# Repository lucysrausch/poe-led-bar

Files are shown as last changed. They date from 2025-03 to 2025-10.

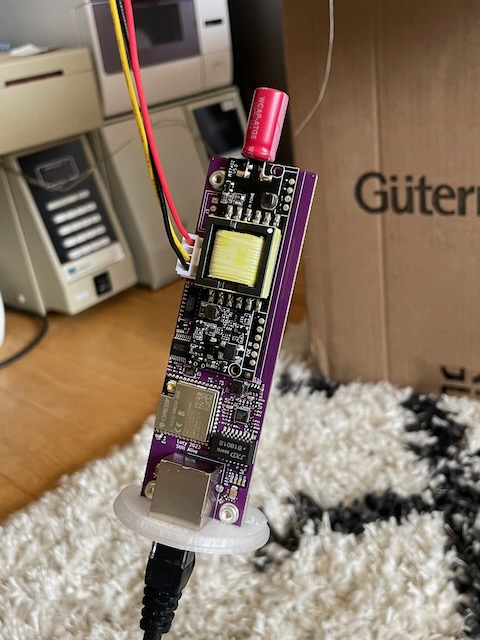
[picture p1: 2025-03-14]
media/pcba.jpeg

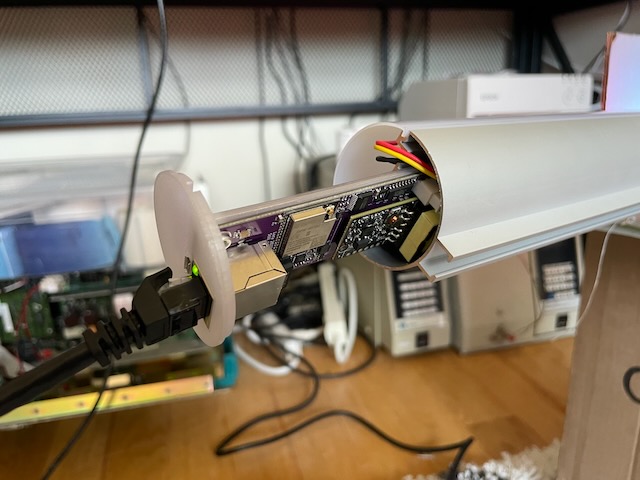
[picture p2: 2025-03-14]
media/cover.jpeg

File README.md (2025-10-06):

# poe-led-bar

Important! I did not have a chance to write docs for this project yet, so:
The hardware is proven at this point and people have successfully ordered and used PCBs based off this repo, with one exception.

The PCB design has a minor bug with the polarity of one of the LEDs inside the ethernet jack.
In rev1.0 of the PCB design, this is not only causing the LED to not work but also the entire ethernet link, because the LEDs are also used as strapping pins to configure the PHY.

The workaround I used is to use this RJ45 jack, which has a bicolor LED so polarity doesn't matter:
https://www.digikey.com/en/products/detail/adam-tech/MTJ-88TX1-FSD-LV/9832786
You could use https://www.digikey.com/en/products/detail/adam-tech/MTJ-88TX1-LV/9832558 which is in stock.

If you dont particularly care about the LEDs in the jack, you can also just get a passive jack without LEDs and solder a 1k SMD resistor across the pads for the LEDs. That should also work fine to configure the PHY.

I will fix this in a future release so more common jacks like the ones stocked at JLC and LCSC can be used.

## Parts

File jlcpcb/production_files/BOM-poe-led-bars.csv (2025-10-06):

Comment | Designator | Footprint | LCSC
FB | FB1 | C_0603 | C1002
1k | R11,R19,R41,R42 | R_0402 | C11702
100n | C1,C15,C20,C21,C25,C3,C5 | C_0402 | C1525
27p | C26,C27 | C_0402 | C1557
100n 100V | C6,C7,C8,C9 | C_0603 | C15725
4u7 | L2 | L_Bourns-SRN4018 | C167828
22k1 | R32 | R_0402 | C170263
4u7 | C16,C19 | C_0603 | C19666
22 | R12,R13,R14,R15,R16,R18,R27,R30,R31,R33,R34,R5 | R_0402 | C25092
49R9 | R6,R7,R8,R9 | R_0402 | C25120
75R | R21,R22,R23,R24 | R_0402 | C25133
100k | R29 | R_0402 | C25741
10k | R10,R25,R26,R28,R39,R40 | R_0402 | C25744
12k1 | R20 | R_0402 | C25852
3k3 | R1,R17,R2,R3,R4 | R_0402 | C25890
Fiducial_0.5mm_Mask1.5mm | MH1,MH2,MH3 | Fiducial_0.5mm_Mask1.5mm | C2915633
RJ45_LED_Shielded | J1 | DNP
BC817-40(SOT23) | Q1,Q3 | SOT-23 | C380921
LAN8720A | U2 | QFN-24-1EP_4x4mm_P0.5mm_EP2.6x2.6mm | C45223
TG111-MSC13LF | TR1 | XFMR_H1102NLT | C510548
1u | C2,C4 | C_0402 | C52923
ESP32-WROOM | U1 | ESP32-WROOM-32U | C701345
4104 | U5 | SO-16_3.9x9.9mm_P1.27mm | C7531
CH340T(SSOP20W) | U6 | SSOP-20W | C8689
SY8120B | U3 | SOT-23-6 | C88474
1nF 2kV | C11,C12 | C_1206_3216Metric | C9196
10u | C10,C14,C17,C18 | C_0603 | C96446
Q12MHz/20pF/10ppm/4P/3.2x2.5mm | Q2 | Crystal_SMD_3225-4Pin_3.2x2.5mm | C97231
LED | J3 | JST_XH_B4B-XH-A_1x04_P2.50mm_Vertical
LED | J2 | JST_XH_B4B-XH-A_1x04_P2.50mm_Vertical
RT7402 | PS1 | Converter_DCDC_XP_POWER-IAxxxxD_THT

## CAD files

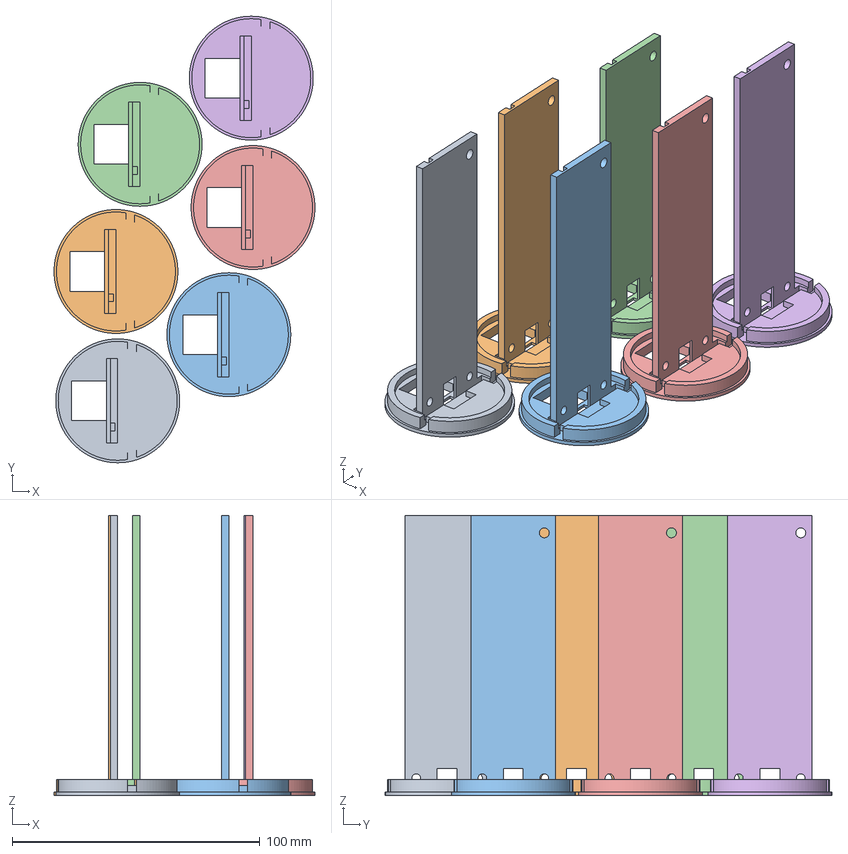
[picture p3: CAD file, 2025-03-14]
cad/poe-cap-pcb.3mf
105.3 x 180.2 x 113.0 mm
poe-cap-pcb.stl x 6

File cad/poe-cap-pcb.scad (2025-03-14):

$fn = 100;

cap_thichkness = 1.5;
base_thickness = 3;
pcb_thickness = 1.6;

difference() {
    union() {
        difference() {
            translate([0, 0, cap_thichkness])cylinder(h = 5, d = 48.0);
            translate([0, 0, cap_thichkness+2.5])cylinder(h = 5, d = 42.5);
        }
        
        cylinder(h = cap_thichkness, d = 50);
        
        rotate([0, 0, 180])translate([0, -17, 1])cube([base_thickness, 34, 112]);
        //rotate([0, 0, 180])translate([base_thickness, -17, 1+112])cube([pcb_thickness, 34, 1]);
        
        

    }
    
    //rotate([0, 0, 180])translate([base_thickness, -25, cap_thichkness+2.5])cube([50, 50, 10]);
    translate([4, -30, cap_thichkness])cube([3.5, 60, 8]);
    translate([0, -40/2, cap_thichkness])cube([7.5, 40, 8]);
    
    //rj45
    rotate([0, 0, 180])translate([base_thickness+pcb_thickness, -16/2, -0.1])cube([14, 16, 6]);
    
    //usb
    rotate([0, 0, 180])translate([base_thickness-3, -8/2, -0.1])cube([3, 8, 5+6]);
    
    //pcb
    rotate([0, 0, 180])translate([base_thickness, -17, 1])cube([pcb_thickness, 34, 5]);
    
    //holes
    translate([0, -12.5, 1+6])rotate([0, -90, 0])cylinder(h = 5, d = 3.5);
    translate([0, 12.5, 1+6])rotate([0, -90, 0])cylinder(h = 5, d = 3.5);
    translate([0, 12.5, 1+105])rotate([0, -90, 0])cylinder(h = 5, d = 4);
    
    //tht
    rotate([0, 0, 180])translate([base_thickness-2, -18/2, 1])cube([2, 18, 5+20]);
    rotate([0, 0, 180])translate([base_thickness-2, -15+0.9, 1+74])cube([2, 3.2, 1+25]);
    rotate([0, 0, 180])translate([base_thickness-2, 9, 1+50])cube([2, 3.2, 5+17]);
    rotate([0, 0, 180])translate([base_thickness-2, 9, 1+99])cube([2, 3.2, 5+8]);
    
    //sma
    //translate([-10/2-pcb_thickness-base_thickness, -15, cap_thichkness+0.5])rotate([0, 0, 90])cylinder(d=9.5, h=7, $fn=6);
     //translate([-10/2-pcb_thickness-base_thickness, -15, 0])rotate([0, 0, 90])cylinder(d=6.4, h=10);



}

translate([2.5, 7, cap_thichkness])cube([7.5, 11, 2.5]);
translate([2.5, -7-11, cap_thichkness])cube([7.5, 11, 2.5]);

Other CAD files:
cad/poe-cap-pcb.stl

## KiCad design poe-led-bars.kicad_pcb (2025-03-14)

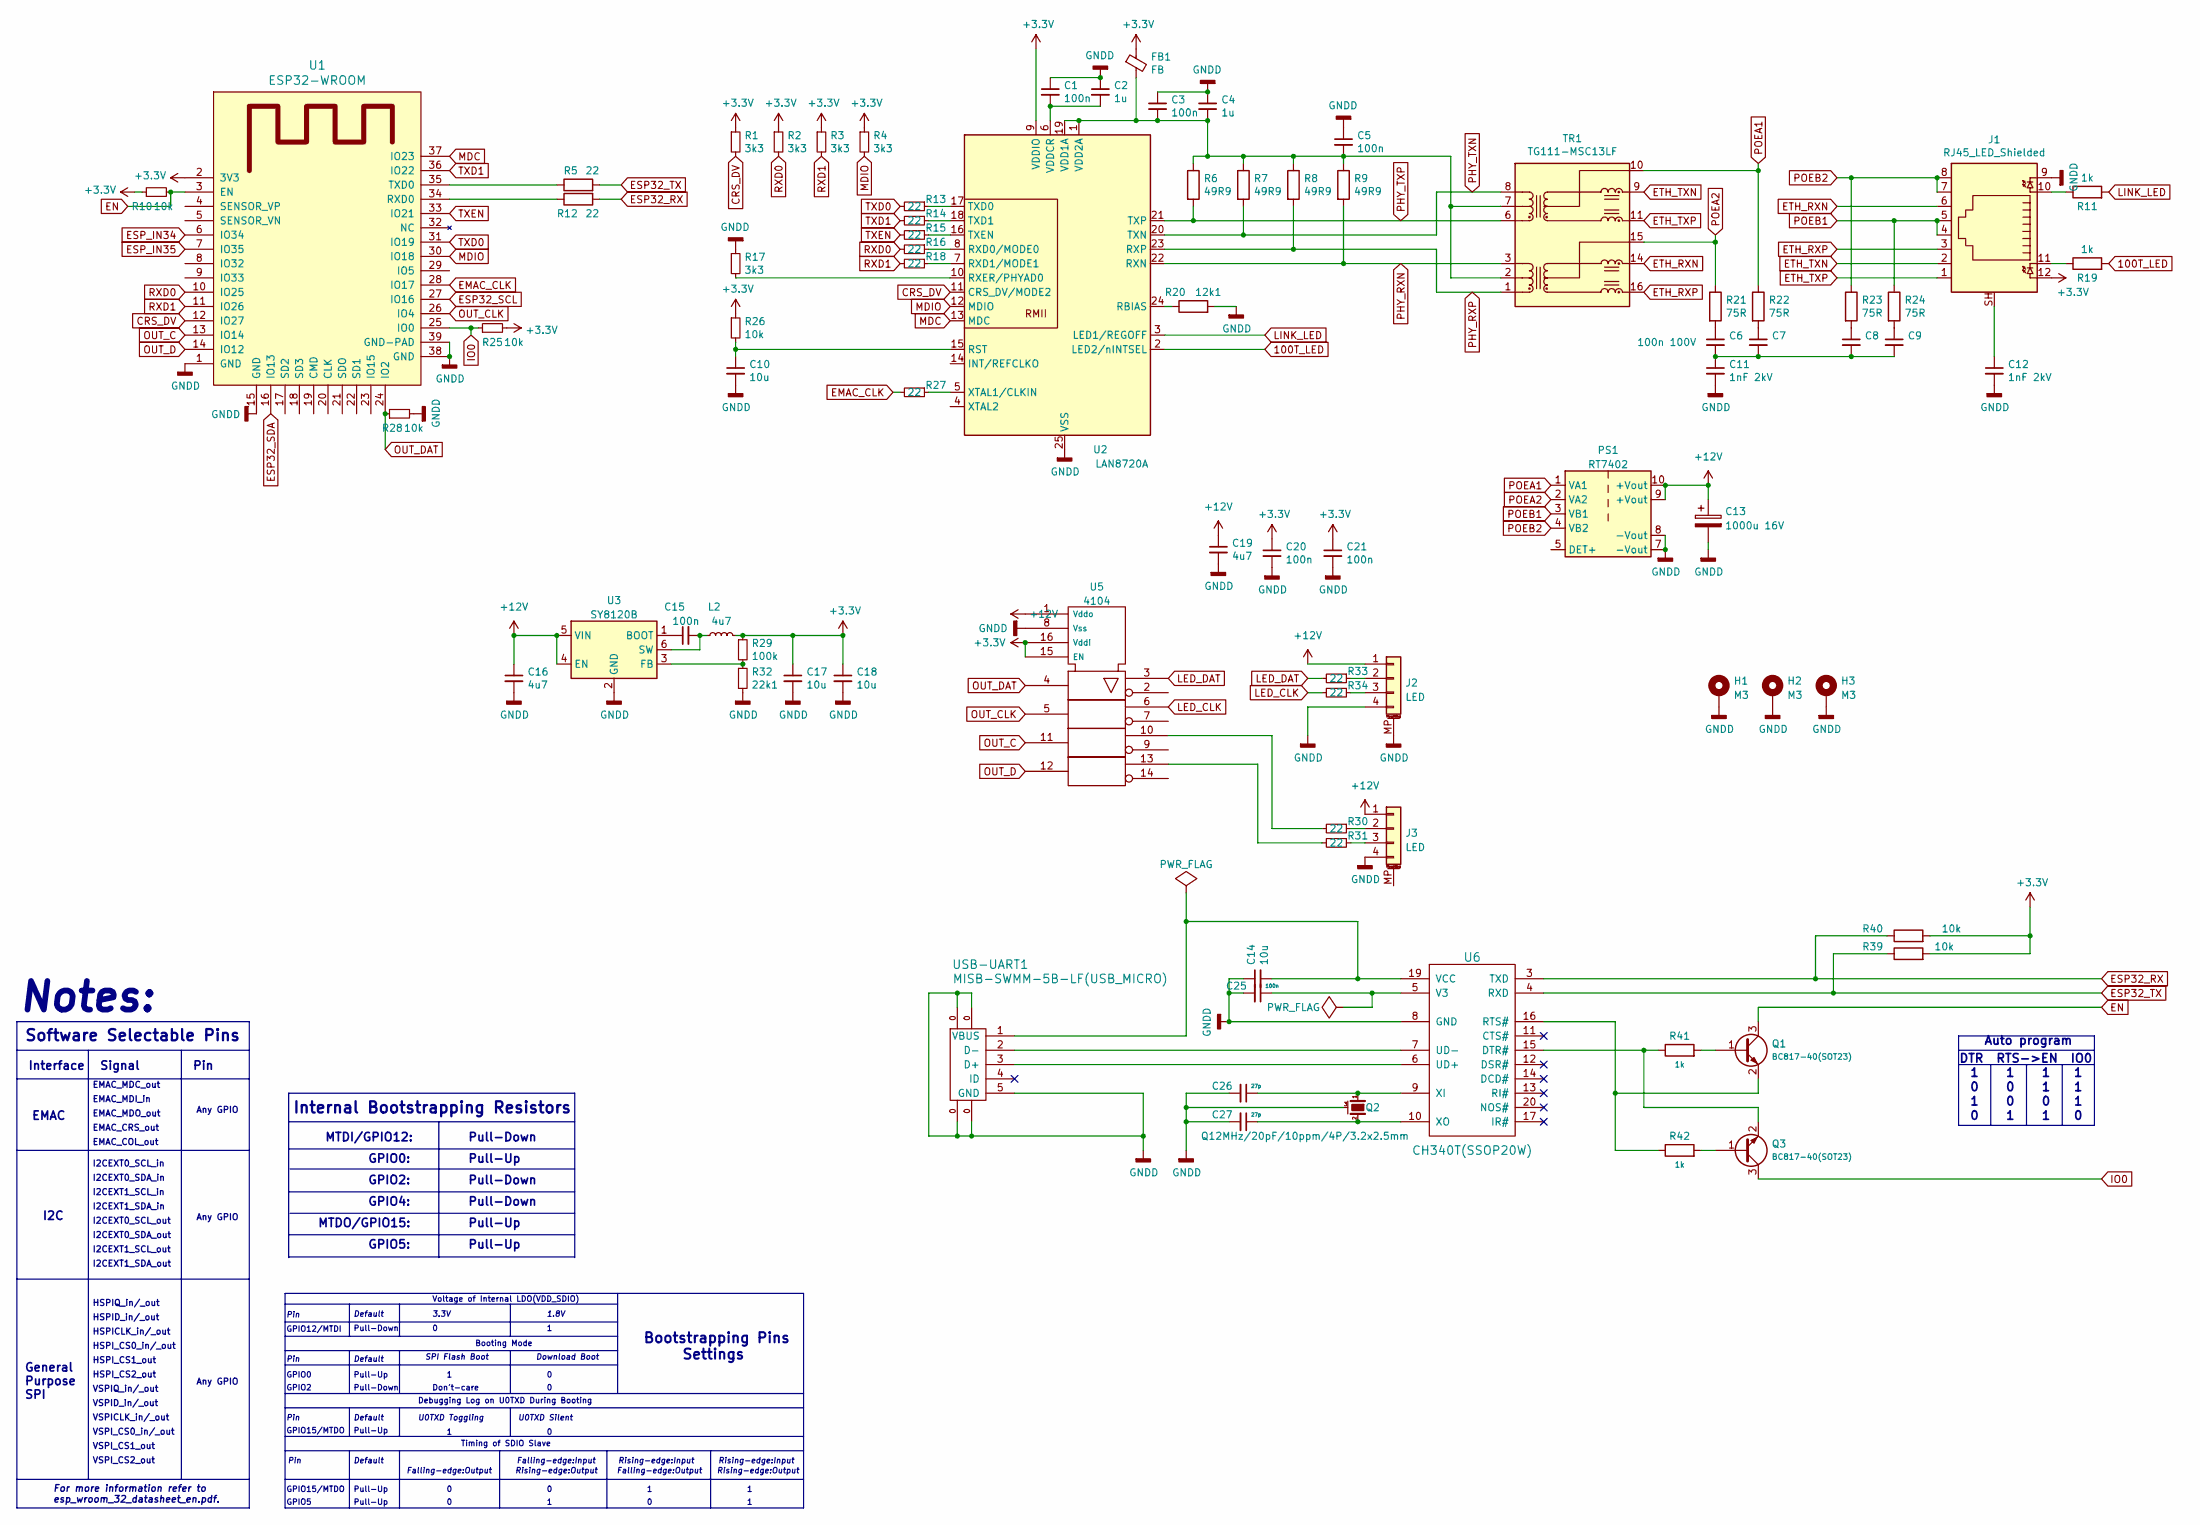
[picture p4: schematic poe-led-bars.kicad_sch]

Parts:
C1, C3, C5, C15, C20, C21, C25: 100n; C_0402
C2, C4: 1u; C_0402
C6, C7, C8, C9: 100n 100V; C_0603
C10, C14, C17, C18: 10u; C_0603
C11, C12: 1nF 2kV; C_1206_3216Metric
C13: 1000u 16V
C16, C19: 4u7; C_0603
C26, C27: 27p; C_0402
FB1: FB; L_0402
H1, H2, H3: M3
J1: RJ45_LED_Shielded; RJ45_Cetus_J1B1211CCD_Horizontal
J2, J3: LED
L2: 4u7
PS1: RT7402; Converter_DCDC_XP_POWER-IAxxxxD_THT
Q1, Q3: BC817-40(SOT23); SOT-23
Q2: Q12MHz/20pF/10ppm/4P/3.2x2.5mm; TSX-3.2x2.5mm_GND(3)
R1, R2, R3, R4, R17: 3k3; R_0402
R5, R12, R13, R14, R15, R16, R18, R27, R30, R31, R33, R34: 22; R_0402
R6, R7, R8, R9: 49R9; R_0402
R10, R25, R26, R28, R39, R40: 10k; R_0402
R11, R19, R41, R42: 1k; R_0402
R20: 12k1; R_0402
R21, R22, R23, R24: 75R; R_0402
R29: 100k; R_0402
R32: 22k1; R_0402
TR1: TG111-MSC13LF; XFMR_H1102NLT
U1: ESP32-WROOM; ESP32-WROOM-32U
U2: LAN8720A; QFN-24-1EP_4x4mm_P0.5mm_EP2.6x2.6mm
U3: SY8120B; SOT-23-6
U5: 4104; SO-16_3.9x9.9mm_P1.27mm
U6: CH340T(SSOP20W); SSOP-20W
USB-UART1: MISB-SWMM-5B-LF(USB_MICRO); USB-MICRO_MISB-SWMM-5B_LF

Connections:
100T_LED: R19.2, U2.2 (LED2/nINTSEL)
+3V3: C17.1, C18.1, C20.1, C21.1, FB1.1, J1.12, L2.2, R1.1, R2.1, R3.1, R4.1, R10.1, R25.2, R26.1, R29.1, R39.2, R40.2, U1.2 (3V3), U2.9 (VDDIO), U5.15 (EN), U5.16 (Vddi)
+12V: C13.1, C16.1, C19.1, J2.1, J3.1, PS1.9 (+Vout), PS1.10 (+Vout), U3.4 (EN), U3.5 (VIN), U5.1 (Vddo)
CRS_DV: R1.2, U1.12 (IO27), U2.11 (CRS_DV/MODE2)
EMAC_CLK: R27.2, U1.28 (IO17)
EN: Q1.3 (C), R10.2, U1.3 (EN)
ESP32_RX: R12.2, R40.1, U6.3 (TXD)
ESP32_SCL: U1.27 (IO16)
ESP32_SDA: U1.16 (IO13)
ESP32_TX: R5.2, R39.1, U6.4 (RXD)
ESP_IN34: U1.6 (IO34)
ESP_IN35: U1.7 (IO35)
ETH_RXN: J1.6, TR1.14 (MTX2-)
ETH_RXP: J1.3, TR1.16 (MTX2+)
ETH_TXN: J1.2, TR1.9 (MTX2-)
ETH_TXP: J1.1, TR1.11 (MTX2+)
GNDD: C1.1, C2.1, C3.1, C4.1, C5.1, C10.2, C11.2, C12.2, C13.2, C14.1, C16.2, C17.2, C18.2, C19.2, C20.2, C21.2, C25.2, C26.2, C27.2, H1.1, H2.1, H3.1, J1.9, J2.4, J2.MP (MountPin), J3.4, PS1.7 (-Vout), PS1.8 (-Vout), Q2.3 (case), R17.1, R20.2, R28.2, R32.2, U1.1 (GND), U1.15 (GND), U1.38 (GND), U1.39 (GND-PAD), U2.25 (VSS), U3.2 (GND), U5.8 (Vss), U6.8 (GND), USB-UART1.0, USB-UART1.5 (GND)
IO0: Q3.3 (C), R25.1, U1.25 (IO0)
LED_CLK: R34.2, U5.6
LED_DAT: R33.2, U5.3
LINK_LED: R11.2, U2.3 (LED1/REGOFF)
MDC: U1.37 (IO23), U2.13 (MDC)
MDIO: R4.2, U1.30 (IO18), U2.12 (MDIO)
unnamed: C1.2, C2.2, U2.6 (VDDCR)
unnamed: C3.2, C4.2, C5.2, FB1.2, R6.1, R7.1, R8.1, R9.1, TR1.2 (TCT2), TR1.7 (TCT2), U2.1 (VDD2A), U2.19 (VDD1A)
unnamed: C6.1, R21.2
unnamed: C7.1, R22.2
unnamed: C8.1, R23.2
unnamed: C9.1, R24.2
unnamed: C10.1, R26.2, U2.15 (RST)
unnamed: C6.2, C7.2, C8.2, C9.2, C11.1
unnamed: C12.1, J1.SH
unnamed: C14.2, U6.19 (VCC), USB-UART1.1 (VBUS)
unnamed: C15.1, U3.1 (BOOT)
unnamed: C15.2, L2.1, U3.6 (SW)
unnamed: C25.1, U6.5 (V3)
unnamed: C26.1, Q2.1, U6.9 (XI)
unnamed: C27.1, Q2.2, U6.10 (XO)
unnamed: J1.10, R11.1
unnamed: J1.11, R19.1
unnamed: J2.2, R33.1
unnamed: J2.3, R34.1
unnamed: J3.2, R30.1
unnamed: J3.3, R31.1
unnamed: Q1.1 (B), R41.2
unnamed: Q1.2 (E), R42.1, U6.16 (RTS#)
unnamed: Q3.1 (B), R42.2
unnamed: Q3.2 (E), R41.1, U6.15 (DTR#)
unnamed: R5.1, U1.35 (TXD0)
unnamed: R12.1, U1.34 (RXD0)
unnamed: R13.1, U2.17 (TXD0)
unnamed: R14.1, U2.18 (TXD1)
unnamed: R15.1, U2.16 (TXEN)
unnamed: R16.1, U2.8 (RXD0/MODE0)
unnamed: R17.2, U2.10 (RXER/PHYAD0)
unnamed: R18.1, U2.7 (RXD1/MODE1)
unnamed: R20.1, U2.24 (RBIAS)
unnamed: R27.1, U2.5 (XTAL1/CLKIN)
unnamed: R29.2, R32.1, U3.3 (FB)
unnamed: R30.2, U5.10
unnamed: R31.2, U5.13
unnamed: U6.6 (UD+), USB-UART1.3 (D+)
unnamed: U6.7 (UD-), USB-UART1.2 (D-)
OUT_C: U1.13 (IO14), U5.11
OUT_CLK: U1.26 (IO4), U5.5
OUT_D: U1.14 (IO12), U5.12
OUT_DAT: R28.1, U1.24 (IO2), U5.4
PHY_RXN: R9.2, TR1.3 (TD2-), U2.22 (RXN)
PHY_RXP: R8.2, TR1.1 (TD2+), U2.23 (RXP)
PHY_TXN: R7.2, TR1.8 (TD2-), U2.20 (TXN)
PHY_TXP: R6.2, TR1.6 (TD2+), U2.21 (TXP)
POEA1: PS1.1 (VA1), R22.1, TR1.10 (MCT2)
POEA2: PS1.2 (VA2), R21.1, TR1.15 (MCT2)
POEB1: J1.4, J1.5, PS1.3 (VB1), R24.1
POEB2: J1.7, J1.8, PS1.4 (VB2), R23.1
RXD0: R2.2, R16.2, U1.10 (IO25)
RXD1: R3.2, R18.2, U1.11 (IO26)
TXD0: R13.2, U1.31 (IO19)
TXD1: R14.2, U1.36 (IO22)
TXEN: R15.2, U1.33 (IO21)

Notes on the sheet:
Internal Bootstrapping Resistors
Pull-Up
I2CEXT0_SDA_out
Signal
Booting Mode
Rising-edge:Output
Download Boot
Any GPIO
1.8V
HSPI_CS1_out
Default
GPIO5:
Auto program
Pin
3.3V
GPIO5
Don't-care
GPIO15/MTDO
VSPIQ_in/_out
EMAC_CRS_out
HSPI_CS0_in/_out
GPIO0:
Debugging Log on U0TXD During Booting
I2CEXT0_SDA_in
I2CEXT0_SCL_out
I2C
General Purpose SPI
HSPI_CS2_out
Pull-Down
Software Selectable Pins
I2CEXT0_SCL_in
VSPI_CS0_in/_out
Falling-edge:Input
Voltage of Internal LDO(VDD_SDIO)
Notes:
GPIO2
Rising-edge:Input
VSPI_CS1_out
MTDO/GPIO15:
EMAC_MDI_in

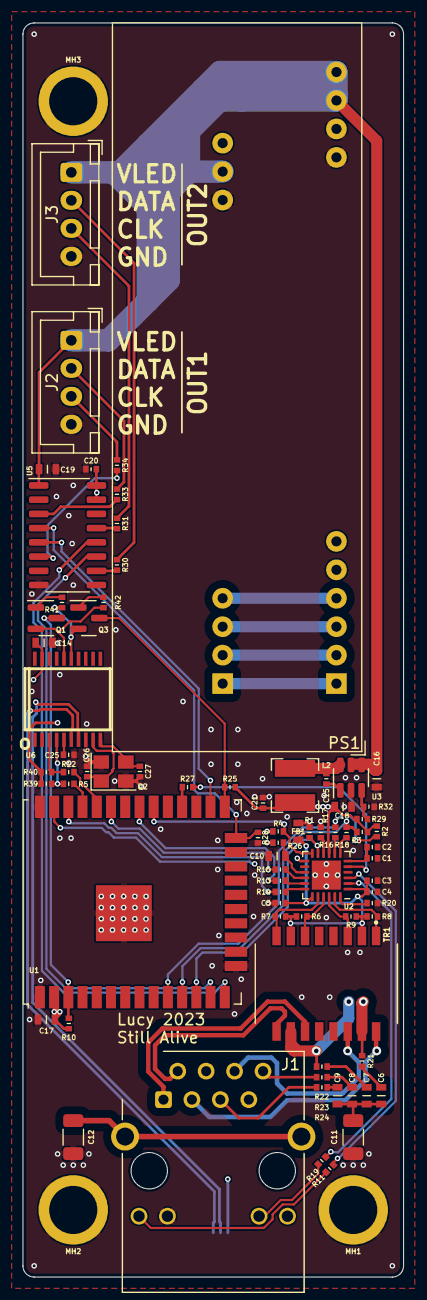
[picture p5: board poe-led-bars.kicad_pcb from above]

Board: 4 copper layers, 34.0 x 112.0 mm, 80 parts (1 on the bottom side), 76 nets.

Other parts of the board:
MH1, MH2, MH3: Fiducial_0.5mm_Mask1.5mm

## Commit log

2025-03-14 ADD: pictures and assembly / demo videos :p
    [poe-led-bars-B_Cu.gbr, poe-led-bars-B_Mask.gbr, poe-led-bars-B_Paste.gbr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]
2025-10-06 Update BOM-poe-led-bars.csv to remove wrong RJ45 part
    [BOM-poe-led-bars.csv]
